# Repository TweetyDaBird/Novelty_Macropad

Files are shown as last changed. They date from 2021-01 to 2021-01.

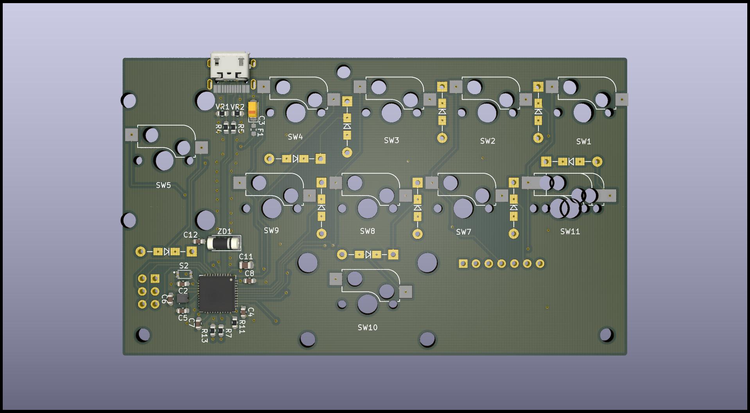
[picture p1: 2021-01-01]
Novelty_macropad_REAR.jpg

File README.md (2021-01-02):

# Novelty_Macropad
 F*ckYou Macropad with 10 keys (ISO Enter, 2.75u Space, 7 pcs 1u + 1 pcs 1u/1.25u Shift)
 
 Inspired by this Reddit thread https://www.reddit.com/r/MechanicalKeyboards/comments/kn0asz/dont_let_your_memes_be_dreams/
 
 * Sub 100x100mm PCB for low cost fabrication
 * Easily soldereable for novice with simple components
 * 10 Cherry MX compatible Kaihl Hot-Swap sockets (with alternate 1u/1.25u layout for shift key)
 * Supports platemounted Cherry style stabilizers
 * Can be used with a ProMicro/EliteC connected to pinheader, or by soldering onboard SMD Atmega32u4 and associated components
 * If used with SMD components, USB-C port (USB2.0)
 * Includes .STEP file of PCB and plate holes for case design
 
 If anyone designs a nice design for a CNC machined or 3D printed case, please let me know (pull), and I'll include the files in the Github.

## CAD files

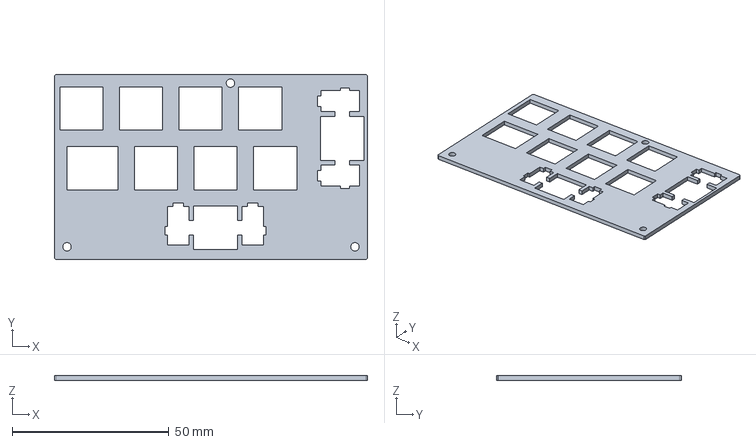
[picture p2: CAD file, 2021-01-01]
plate.step
100.0 x 59.0 x 1.60 mm

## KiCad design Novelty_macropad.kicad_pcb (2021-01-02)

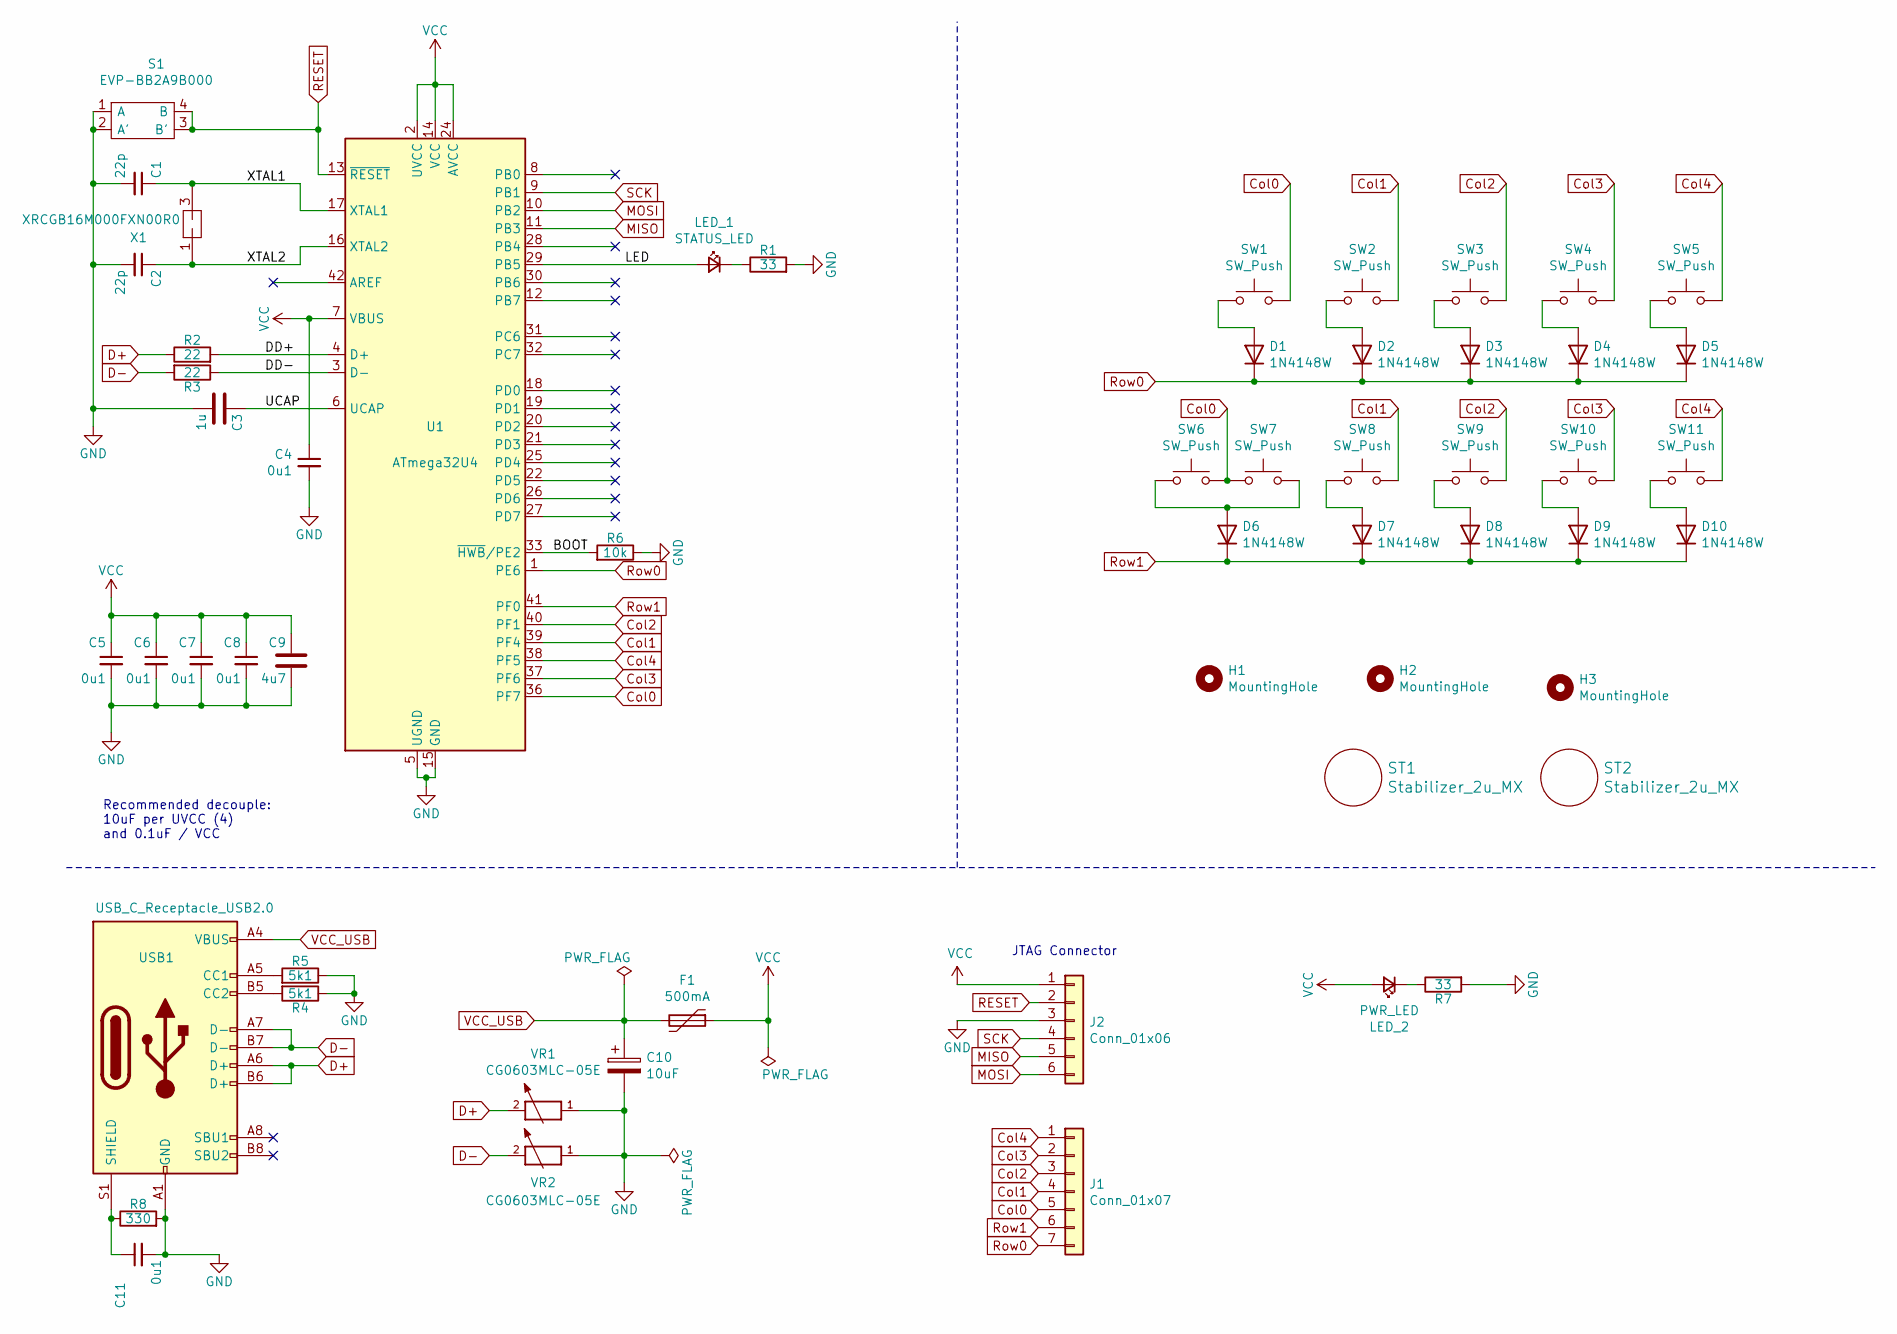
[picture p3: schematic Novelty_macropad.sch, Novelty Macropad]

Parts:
C1, C2: 22p; C_0603_1608Metric; Manufacturer_Part_Number 06035A220JAT2A; Mouser Part Number 581-06035A220J
C3: 1u; C_0805_2012Metric; Manufacturer_Part_Number CL21B105KBFNNNG; Mouser Part Number 187-CL21B105KBFNNNG
C4, C5, C6, C7, C8, C11: 0u1; C_0603_1608Metric; Manufacturer_Part_Number 06035C104JAT2A; Mouser Part Number 581-06035C104JAT2A
C9: 4u7; C_0805_2012Metric; Manufacturer_Part_Number C2012X7R1H475K125AC; Mouser Part Number 810-C2012X7R475K125C
C10: 10uF; CP_EIA-3216-18_Kemet-A; Manufacturer_Part_Number TAJA106M010RNJ; Mouser Part Number 581-TAJA106M010R
D1, D2, D3, D4, D5, D6, D7, D8, D9, D10: 1N4148W; Diode_DO35_SOD123
F1: 500mA; Fuse_0603_1608Metric; Manufacturer_Part_Number 04000025WR; Mouser Part Number 576-04000025WR
H1, H2, H3: MountingHole; MountingHole_2.7mm_M2.5
J1: Conn_01x07; PinHeader_1x07_P2.54mm_Vertical
J2: Conn_01x06; PinHeader_2x03_P2.54mm_Vertical; Manufacturer_Part_Number Pinheader
LED_1: STATUS_LED; LED_0603_1608Metric; Manufacturer_Part_Number APT1608EC; Mouser Part Number 604-APT1608EC
LED_2: PWR_LED; LED_0603_1608Metric; Manufacturer_Part_Number APT1608EC; Mouser Part Number 604-APT1608EC
R1, R7: 33; R_0603_1608Metric; Manufacturer_Part_Number ERJ-3EKF33R0V; Mouser Part Number 667-ERJ-3EKF33R0V
R2, R3: 22; R_0603_1608Metric; Manufacturer_Part_Number ERJ-3GEYJ220V; Mouser Part Number 667-ERJ-3GEYJ220V
R4, R5: 5k1; R_0603_1608Metric; Manufacturer_Part_Number ERJ-3EKF5101V; Mouser Part Number 667-ERJ-3EKF5101V
R6: 10k; R_0603_1608Metric; Manufacturer_Part_Number ERJ-3EKF1002V; Mouser Part Number 667-ERJ-3GEYJ103V
R8: 330; R_0603_1608Metric; Manufacturer_Part_Number ERJ-3EKF3300V; Mouser Part Number 667-ERJ-3EKF3300V
S1: EVP-BB2A9B000; EVPBB2A9B000; Mouser Part Number 667-EVP-BB2A9B000
ST1, ST2: Stabilizer_2u_MX; Stabilizer_MX_2u
SW1, SW2, SW3, SW4, SW5, SW6, SW7, SW8, SW9, SW10, SW11: SW_Push; Kailh_socket_MX
U1: ATmega32U4; QFN-44-1EP_7x7mm_P0.5mm_EP5.15x5.15mm_ThermalVias; Manufacturer_Part_Number ATMEGA32U4RC-MU; Mouser Part Number 556-ATMEGA32U4RC-MU
USB1: USB_C_Receptacle_USB2.0; HRO-TYPE-C-31-M-12-Assembly; Manufacturer_Part_Number HRO-TYPE-C-31-M-14
VR1, VR2: CG0603MLC-05E; R_0603_1608Metric; Mouser Part Number 652-CG0603MLC-05E
X1: XRCGB16M000FXN00R0; XRCGB16M000FXN1R0; Mouser Part Number 81-XRCGB16M000FXN00R

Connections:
/BOOT: R6.2, U1.33 (~HWB~/PE2)
/DD+: R2.2, U1.4 (D+)
/DD-: R3.1, U1.3 (D-)
/LED: LED_1.2 (A), U1.29 (PB5)
/UCAP: C3.1, U1.6 (UCAP)
/XTAL1: C1.1, U1.17 (XTAL1), X1.3
/XTAL2: C2.1, U1.16 (XTAL2), X1.1
Col0: J1.5, SW1.1, SW6.1, SW7.1, U1.36 (PF7)
Col1: J1.4, SW2.1, SW8.1, U1.39 (PF4)
Col2: J1.3, SW3.1, SW9.1, U1.40 (PF1)
Col3: J1.2, SW4.1, SW10.1, U1.37 (PF6)
Col4: J1.1, SW5.1, SW11.1, U1.38 (PF5)
D+: R2.1, USB1.A6 (D+), USB1.B6 (D+), VR1.2
D-: R3.2, USB1.A7 (D-), USB1.B7 (D-), VR2.2
GND: C1.2, C2.2, C3.2, C4.2, C5.2, C6.2, C7.2, C8.2, C9.2, C10.2, C11.2, J2.3, R1.2, R4.1, R5.1, R6.1, R7.2, R8.2, S1.1 (A), S1.2 (A'), U1.5 (UGND), U1.15 (GND), U1.23 (GND), U1.35 (GND), U1.43 (GND), USB1.A1 (GND), USB1.A12 (GND), USB1.B1 (GND), USB1.B12 (GND), VR1.1, VR2.1
MISO: J2.5, U1.11 (PB3)
MOSI: J2.6, U1.10 (PB2)
unnamed: C11.1, R8.1, USB1.S1 (SHIELD)
unnamed: D1.2 (A), SW1.2
unnamed: D2.2 (A), SW2.2
unnamed: D3.2 (A), SW3.2
unnamed: D4.2 (A), SW4.2
unnamed: D5.2 (A), SW5.2
unnamed: D6.2 (A), SW6.2, SW7.2
unnamed: D7.2 (A), SW8.2
unnamed: D8.2 (A), SW9.2
unnamed: D9.2 (A), SW10.2
unnamed: D10.2 (A), SW11.2
unnamed: LED_1.1 (K), R1.1
unnamed: LED_2.1 (K), R7.1
unnamed: R4.2, USB1.B5 (CC2)
unnamed: R5.2, USB1.A5 (CC1)
RESET: J2.2, S1.3 (B'), S1.4 (B), U1.13 (~RESET)
Row0: D1.1 (K), D2.1 (K), D3.1 (K), D4.1 (K), D5.1 (K), J1.7, U1.1 (PE6)
Row1: D6.1 (K), D7.1 (K), D8.1 (K), D9.1 (K), D10.1 (K), J1.6, U1.41 (PF0)
SCK: J2.4, U1.9 (PB1)
VCC: C4.1, C5.1, C6.1, C7.1, C8.1, C9.1, F1.1, J2.1, LED_2.2 (A), U1.2 (UVCC), U1.7 (VBUS), U1.14 (VCC), U1.24 (AVCC), U1.34 (VCC), U1.44 (AVCC)
VCC_USB: C10.1, F1.2, USB1.A4 (VBUS), USB1.A9 (VBUS), USB1.B4 (VBUS), USB1.B9 (VBUS)

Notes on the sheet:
Recommended decouple: 10uF per UVCC (4) and 0.1uF / VCC
JTAG Connector

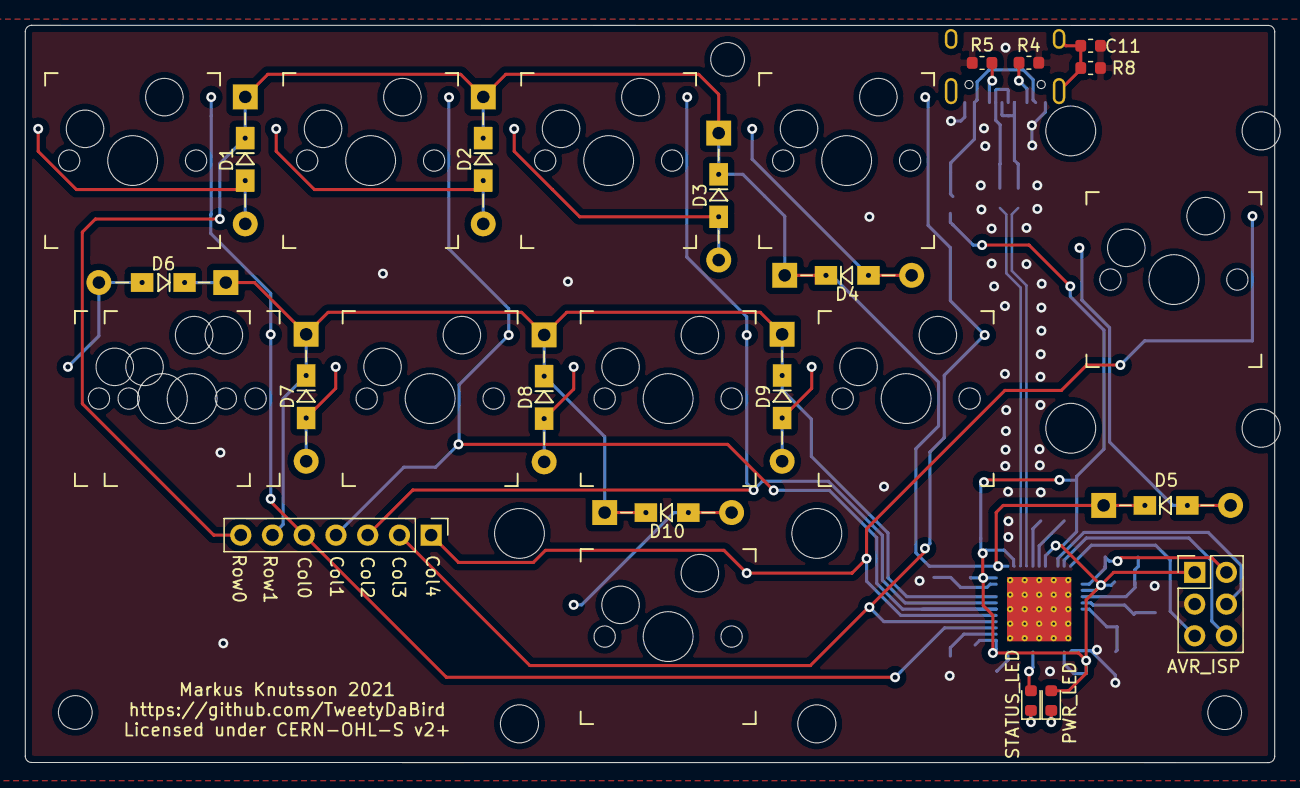
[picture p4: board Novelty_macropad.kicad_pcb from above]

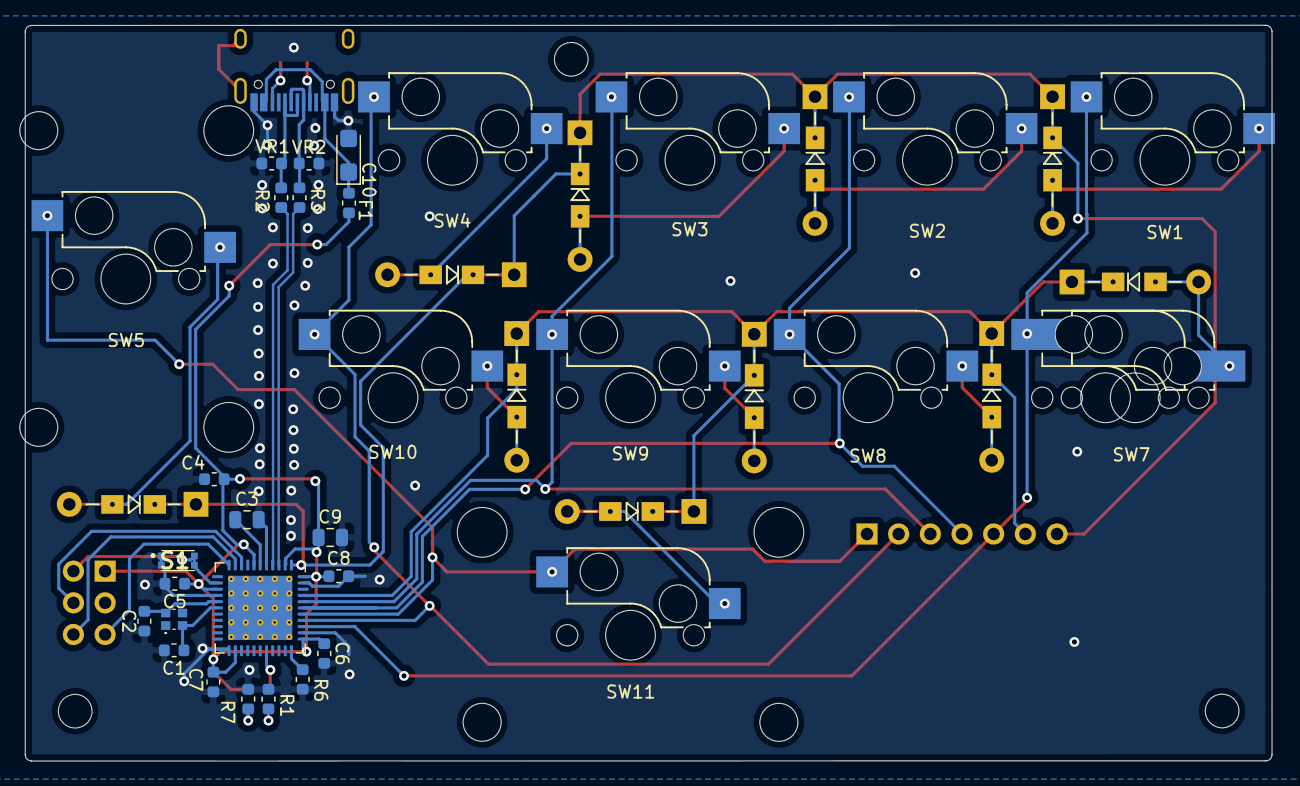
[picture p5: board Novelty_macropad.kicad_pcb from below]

Board: 2 copper layers, 100.0 x 59.0 mm, 56 parts (22 on the bottom side), 38 nets.

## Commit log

2021-01-01 initial design
    [Novelty_macropad.kicad_pcb, Novelty_macropad.sch, file60039BC7.sch]
2021-01-01 plate added, step files
    [Novelty_macropad.kicad_pcb, Novelty_macropad.sch, file60039BC7.sch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]
2021-01-02 Corrected silkscreen and markings
    [Novelty_macropad.kicad_pcb, Novelty_macropad.sch, plate.kicad_pcb]

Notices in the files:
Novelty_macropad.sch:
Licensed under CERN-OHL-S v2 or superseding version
